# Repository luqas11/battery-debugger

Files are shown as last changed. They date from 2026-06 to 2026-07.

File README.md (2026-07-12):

# battery-debugger

A system for tracking the health of a lead-acid battery over time, by periodically measuring its discharge curve under a constant load. Comparing curves taken months apart reveals how much capacity the battery has lost.

## How it works

A discharge test goes like this:

1. Connect a fixed load and the ESP8266 board to the battery terminals.
2. Open the backend web UI and start a new test, entering the date, the load current, and the battery's age in months.
3. The ESP takes periodic voltage readings and sends them to the backend, which computes the elapsed time since the test started and saves both values to a CSV file.
4. Once the battery is depleted, stop the test from the web UI.
5. Push the new records to the repository — the dashboard on GitHub Pages updates automatically.

## Parts of the project

### `firmware/`

An Arduino sketch for the **ESP8266** that periodically reads the battery voltage through the analog input and sends it to the backend. The WiFi credentials, the backend URL, and the reading interval are configured at runtime via a built-in setup portal, with no reflashing needed. Two external LEDs indicate the connection and reading status. See [`firmware/README.md`](firmware/README.md) for setup, wiring, and calibration details.

### `circuit/`

KiCad schematic for the circuit that connects the ESP8266 board to the battery terminals, plus a 3D-printable case. A PDF export of the schematic is available at [`circuit/circuit-schematic.pdf`](circuit/circuit-schematic.pdf). See [`circuit/README.md`](circuit/README.md) for details.

### `backend/`

A **Go** backend (single static binary) that exposes an HTTP API to start and stop tests and receive voltage readings, and serves a web UI to control everything from a browser. It runs on the machine where records are stored. Supports Linux (32-bit and 64-bit) and Windows. See [`backend/README.md`](backend/README.md).

### `frontend/`

A **Go** tool that reads the `records/` folder and generates a static dashboard, published to **GitHub Pages**. The dashboard lets you compare discharge curves between tests and visualize battery capacity decay over time. See [`frontend/README.md`](frontend/README.md).

### `records/`

CSV and JSON files for every finished test. Each test produces a `<name>.csv` (time/voltage readings) and a `<name>.json` (date, current, battery age, and an `outlier` flag that excludes anomalous tests from the capacity decay chart). This folder is the single source of data for both the backend and the dashboard.

## Running the backend

Prebuilt binaries are in `backend/binaries/`. Run the one that matches your machine:

```
# Linux 32-bit
./backend/binaries/backend-386

# Linux 64-bit
./backend/binaries/backend-amd64

# Windows
.\backend\binaries\backend.exe
```

On Linux, mark the binary as executable first if needed: `chmod +x backend/binaries/backend-386`.

Once running, open `http://<host>:8000/` in a browser to access the web UI.

## Viewing the dashboard

The dashboard is published automatically to GitHub Pages on every push to `main` that modifies `records/` or `frontend/`. To view it locally, run:

```
./frontend/binaries/frontend.exe        # Windows
./frontend/binaries/frontend-amd64     # Linux 64-bit
./frontend/binaries/frontend-386       # Linux 32-bit
```

Then open `http://localhost:8001/`.

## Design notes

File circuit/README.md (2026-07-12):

# Circuit

KiCad schematic for the circuit that connects the ESP8266 board to the battery terminals. A PDF export is available at [`circuit-schematic.pdf`](circuit-schematic.pdf).

## What it does

- **Voltage divider** (R1 10k / R2 56k) scales the battery voltage down to a range the ESP8266's analog input (`A0`) can read safely. The firmware converts the raw ADC reading back to the real battery voltage using the `REF_VOLTAGE`/`REF_ADC` calibration constants — see [`../firmware/README.md`](../firmware/README.md).
- **Two status LEDs** (green and red), each behind a 220 Ω current-limiting resistor, connected to GPIO4 and GPIO12. These indicate the WiFi connection and last-reading status — see the LED indicators table in [`../firmware/README.md`](../firmware/README.md).
- **J1** is the two-pin connector to the battery terminals.

## Case

`Case.scad` is an OpenSCAD model for a 3D-printable enclosure, with `Case_Base.stl` and `Case_Lid.stl` as the exported, ready-to-print parts.

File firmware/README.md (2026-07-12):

# Firmware

An Arduino sketch for the **ESP8266** that periodically reads the battery voltage through the analog input and sends it to the backend, at a configurable interval (2 minutes by default).

## Setup

### 1. Configure the setup access point

Copy `config.example.h` to `config.h` and set the SSID and password for the access point the ESP exposes when configuring WiFi:

```cpp
#define AP_SSID     "SSID"
#define AP_PASSWORD "PASSWORD"
```

The password must be at least 8 characters (WPA2 requirement). `config.h` is gitignored and never committed.

### 2. Flash the sketch

Open `firmware.ino` in the Arduino IDE, select your ESP8266 board, and upload.

### 3. Configure via the setup portal

On first boot, the ESP starts a WiFi network using the SSID and password from `config.h`. Connect to it and open `http://192.168.4.1` in a browser.

The page has two independent configuration sections:

- **Configurar WiFi** — enter your network's SSID and password and press **Guardar**. The ESP saves the credentials and connects. Leaving the password field blank when re-saving the same network keeps the previously saved password.
- **Configurar backend** — enter the host and port of the machine running the backend (e.g. `192.168.1.42:8000`) and the reading interval in minutes, then press **Guardar**. The interval takes effect immediately, without a restart.

The setup portal stays available at `http://192.168.4.1` after a successful connection, so you can check the connection status, see the ESP's IP on the local network, or update any setting without reflashing.

## Voltage calibration

The voltage is converted from the ADC reading using two calibration constants defined directly in `firmware.ino`:

```cpp
const float REF_VOLTAGE = 11.46;  // known input voltage in Volts
const int   REF_ADC     = 566;    // ADC reading at that voltage
```

The conversion is: `voltage = analogRead(A0) * (REF_VOLTAGE / REF_ADC)`

To recalibrate, apply a known voltage to the input (close to the voltages you expect to measure for best accuracy), read the raw ADC value from the Serial monitor, and update both constants.

## LED indicators

The firmware uses two external LEDs connected to GPIO4 (green) and GPIO12 (red). Wire each LED with a resistor (~220–330 Ω) between the GPIO pin and the anode; connect the cathode to GND.

| Green LED | Red LED | Meaning |
|---|---|---|
| Blinking | Off | Connecting to WiFi |
| Solid | Off | Connected, last reading OK |
| Solid | Blinking | Connected, error sending last reading |
| Off | Solid | No WiFi connection |

## Dependencies

- **ArduinoJson 7.4.3** (Benoit Blanchon) — available in the Arduino Library Manager
- **ESP8266 Arduino Core 3.1.2** (ESP8266 Community) — available in the Arduino Boards Manager

If the code fails to compile after reinstalling dependencies, make sure the versions listed above are used.

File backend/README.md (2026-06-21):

# Backend

This **Go** backend handles all the logic related to running and saving battery discharge tests. It has no external dependencies (standard library only), and serves both the **HTTP API** and the **frontend** (embedded via `go:embed`) from a single static binary, with no runtime required on the target machine.

The working flow is the following: when a new test is started, a **CSV** file and a **JSON** metadata file are created, both named by appending the string `current_` to the given test name. Any saved reading is appended to that **CSV** file. When the test is ended, both files are renamed, removing the `current_` prefix. After that, the test's name appears in the test list, and its metadata and readings remain in the `/records` folder.

### API:

`[GET] /get-current-test`

Returns the name of the test that is currently in progress. If a test is in progress, returns:
```json
{
    "currentTestName": "Example",
    "metadata": { "date": "2026-06-14", "current": 0.25, "age": 12, "outlier": false },
    "lastReadings": [
        { "time": 1.50, "voltage": 12.10 },
        { "time": 1.53, "voltage": 12.05 }
    ]
}
```
If not, returns:
```json
{
    "currentTestName": ""
}
```

`[GET] /get-test-list`

Returns a list with the names of the finished tests saved in the `/records` folder. For example:
```json
{
    "testNames": [
        "Example",
        "Example2",
        "Example3"
    ]
}
```

`[POST] /start-test`

Starts a new test on the backend. The given name can only contain numbers, letters and underscores, and cannot be a name already present in the test list. `date` must have the format `YYYY-MM-DD`, and `current`/`age` must be numbers. The request body must be:
```json
{
    "name": "Example",
    "date": "2026-06-14",
    "current": 0.25,
    "age": 12
}
```

`[POST] /save-reading`

Saves a voltage reading to the current test file. The request body must be:
```json
{
    "voltage": 12.0
}
```

The time elapsed since the test started is computed by the backend and written to the CSV alongside the voltage. This makes the recorded time independent of when the ESP was booted, and robust to ESP reboots mid-test.

`[POST] /end-test`

Ends the test that is currently in progress.

### Development notes:

To run the app in development:
```
go run .
```

The server listens on port `8000` by default, on all network interfaces. This can be configured with environment variables:
- `PORT` — port to listen on (default `8000`)
- `HOST` — interface to bind to (default empty, i.e. all interfaces)

For example, to use a different port:
```
PORT=9000 go run .
```

### Building:

The app compiles to a single static binary, with no external dependencies. Always build with `CGO_ENABLED=0` to ensure the binary doesn't link against system libraries.

Prebuilt binaries for the supported targets are kept in the `binaries/` folder:

| Target | Binary | Build command |
|---|---|---|
| Ubuntu (32-bit, `i686`) | `binaries/backend-386` | `CGO_ENABLED=0 GOOS=linux GOARCH=386 go build -o binaries/backend-386 .` |
| Ubuntu (64-bit, `x86_64`) | `binaries/backend-amd64` | `CGO_ENABLED=0 GOOS=linux GOARCH=amd64 go build -o binaries/backend-amd64 .` |
| Windows (64-bit) | `binaries/backend.exe` | `CGO_ENABLED=0 GOOS=windows GOARCH=amd64 go build -o binaries/backend.exe .` |

Any of these binaries can be copied to and run on the corresponding target machine directly, without installing Go or any other dependency. The binary automatically locates the `/records` folder at the project root, whether it's run from `backend/` or from `backend/binaries/`.

### Running:

On Linux, the binary needs execute permissions, which may be lost when copying it from another OS:
```
chmod +x binaries/backend-386
```

To run a binary, either from `backend/`:
```
./binaries/backend-386
```
or from within `backend/binaries/`:
```
./backend-386
```
(on Windows, `.\binaries\backend.exe` or `.\backend.exe` respectively).

Once running, open `http://<host>:<port>/` in a browser (e.g. `http://localhost:8000/` or `http://192.168.1.11:8000/` from another machine on the same network) to access the web UI.

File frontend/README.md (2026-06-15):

# Frontend

This **Go** module generates the data for, and serves, a static dashboard that visualizes the battery discharge tests saved in `/records`: a comparison of voltage curves between tests, and the decay of estimated battery capacity over time.

It has no external dependencies (standard library only). The dashboard uses **Chart.js** loaded from a CDN, with no build step or npm involved.

### How it works:

Running the binary with no arguments does two things:
1. **Generates the data**: reads `/records`, and for every finished test (a matching `<name>.csv` + `<name>.json` pair) copies both files into `frontend/data/`, and writes `frontend/data/manifest.json` with a list of all tests and their metadata.
2. **Serves the dashboard**: starts an HTTP server serving the `frontend/` folder (including the `data/` just generated), so `index.html` can fetch the manifest and CSV/JSON files directly.

`frontend/data/` is regenerated on every run and is not committed to the repository (see `.gitignore`).

Running the binary with the `generate-data` subcommand only performs step 1, without starting the server. This is the mode used by the GitHub Actions workflow that deploys the dashboard to GitHub Pages.

### Development notes:

To run in development (generates data and serves on `:8001`):
```
go run .
```

To only generate `frontend/data/` without serving:
```
go run . generate-data
```

The server listens on port `8001` by default, on all network interfaces. This can be configured with environment variables:
- `PORT` — port to listen on (default `8001`)
- `HOST` — interface to bind to (default empty, i.e. all interfaces)

### Building:

The app compiles to a single static binary, with no external dependencies. Always build with `CGO_ENABLED=0` to ensure the binary doesn't link against system libraries.

Prebuilt binaries for the supported targets are kept in the `binaries/` folder:

| Target | Binary | Build command |
|---|---|---|
| Ubuntu (32-bit, `i686`) | `binaries/frontend-386` | `CGO_ENABLED=0 GOOS=linux GOARCH=386 go build -o binaries/frontend-386 .` |
| Linux (64-bit, used by CI) | `binaries/frontend-amd64` | `CGO_ENABLED=0 GOOS=linux GOARCH=amd64 go build -o binaries/frontend-amd64 .` |
| Windows (64-bit) | `binaries/frontend.exe` | `CGO_ENABLED=0 GOOS=windows GOARCH=amd64 go build -o binaries/frontend.exe .` |

The binary automatically locates `/records` and the `frontend/` folder, whether it's run from `frontend/` or from `frontend/binaries/`.

### Running:

On Linux, the binary needs execute permissions, which may be lost when copying it from another OS:
```
chmod +x binaries/frontend-amd64
```

To run a binary, either from `frontend/`:
```
./binaries/frontend-amd64
```
or from within `frontend/binaries/`:
```
./frontend-amd64
```
(on Windows, `.\binaries\frontend.exe` or `.\frontend.exe` respectively).

Once running, open `http://localhost:8001/` in a browser to view the dashboard.

### Deployment:

The dashboard is published to GitHub Pages via `.github/workflows/deploy-frontend.yml`, which runs on every push to `main` that touches `records/` or `frontend/`. It runs `binaries/frontend-amd64 generate-data` to populate `frontend/data/`, then publishes the `frontend/` folder as a Pages artifact.

For this to work, GitHub Pages must be configured with **Source: GitHub Actions** in the repository settings.

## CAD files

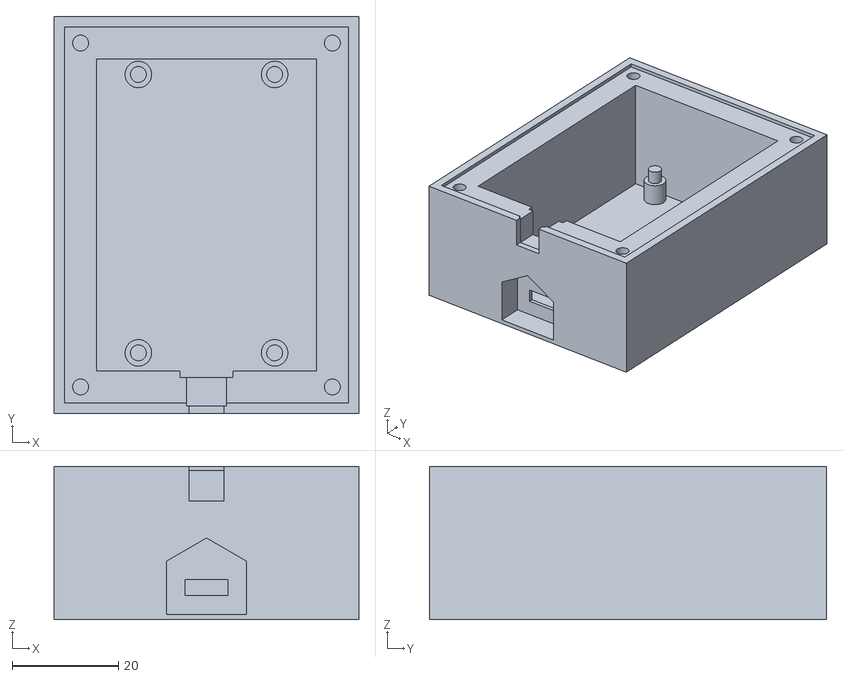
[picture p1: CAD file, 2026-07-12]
circuit/Case_Base.stl
57.3 x 74.6 x 28.8

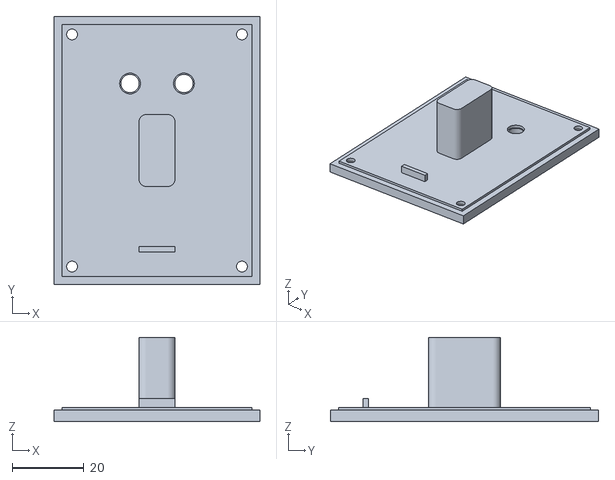
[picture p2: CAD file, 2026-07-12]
circuit/Case_Lid.stl
57.3 x 74.6 x 23.5

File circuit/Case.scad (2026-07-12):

/* ============================================================
   BATTERY DEBUGGER - Case para NodeMCU V3
   ============================================================
   Apertura: tornillos autorroscantes (4 esquinas)
   Sujecion de la placa: tipo "sandwich" sobre postes que tambien
                          centran la placa en X/Y (encajan a
                          presion en los agujeros de montaje)
   LEDs: agujero a presion sin pegamento (escalon que traba el
         reborde/flange del LED)
   Puerto USB: hueco recesado (carcasa del conector macho + agujero
               del tamaño exacto del conector), con ranura de
               montaje oculta detras de una pared fina

   COMO IMPRIMIR:
   Cambia la variable render_part (arriba de todo, antes de los demas
   parametros) para elegir que renderizar/exportar: "base", "lid" o "both".
   Con "both" se dibujan las dos piezas lado a lado, utiles para ver el
   conjunto en preview, pero para exportar STL conviene exportar cada
   pieza por separado (con "base" o "lid").
   ============================================================ */

// ---------- QUE RENDERIZAR ----------
render_part = "both";  // "base" | "lid" | "both"

// ---------- PLACA (NodeMCU V3) ----------
board_length          = 58;     // mm, eje Y (largo)
board_width           = 31.3;   // mm, eje X (ancho)
board_height          = 20;     // mm, altura total con componentes + espacio para cablear LEDs adentro
mount_hole_dia        = 3.2;    // diametro de los agujeros de montaje de la placa
mount_hole_offset_x   = 2.85;   // centro del agujero al borde de la placa, sentido del lado corto (ancho)
mount_hole_offset_y   = 2.6;    // centro del agujero al borde de la placa, sentido del lado largo (largo)
peg_near_usb_extra    = 0.5;    // mm de mas para alejar de la pared los 2 postes del lado del conector
                                 // (sacrifica un poco de alineacion con el agujero real, a cambio de mas margen)

// ---------- TOLERANCIAS Y PAREDES ----------
wall                  = 2.0;    // espesor de pared
board_gap_usb_side    = 0.3;    // juego entre la placa y la cavidad, lado del conector USB -- debe quedar al ras
board_gap_far_side    = board_gap_usb_side;  // lado opuesto al USB -- igual al del USB, para que sea simetrico
board_gap_x_sides     = 5.0;    // margen entre la placa y la cavidad en los 2 lados X (izq/der) -- de sobra, sin ajuste fino
top_clearance         = 1.0;    // espacio libre entre el componente mas alto y la tapa
margin                = 6.0;    // franja libre entre la cavidad y la pared externa (para los postes de tornillo)

// ---------- POSTES DE CENTRADO / STANDOFF (sandwich) ----------
peg_height            = 5.0;    // altura del cilindro ancho (separacion piso<->placa)
peg_base_dia          = 5.0;    // diametro del cilindro ancho (mas resistente, evita que
                                 // los componentes de la placa hagan presion contra el piso)
peg_tip_height        = 3.0;    // altura de la punta fina que entra en el agujero de la placa
peg_tip_dia           = mount_hole_dia - 0.2;  // un poco menor a mount_hole_dia -> encaja a presion
board_thickness       = 1.0;    // espesor real de la PCB (sin componentes, que miran hacia el piso)

// ---------- POSTE DE PRESION (colgante desde la tapa, unico y central) ----------
// Empuja la placa contra los postes de centrado al cerrar, sin ocupar
// espacio en las esquinas ni en la mayor parte del volumen de cableado.
press_post_w          = 10.0;   // ancho del poste de presion (eje X)
press_post_l          = 20.0;   // largo del poste de presion (eje Y)
press_post_corner_r   = 2.0;    // radio de redondeo de los 4 bordes verticales del poste
press_post_overlap    = -0.5;   // mm de mas (o de menos, si es negativo) que el poste se pasa hacia
                                 // la placa -- negativo = queda corto a proposito, para no presionar de mas

// ---------- TORNILLOS AUTORROSCANTES (tapa) ----------
screw_pilot_dia       = 3.0;    // agujero piloto para que el tornillo se muerda
screw_pilot_depth     = 8.0;    // profundidad del agujero piloto dentro del poste
screw_shaft_clear_dia = 3.0;    // hueco en la tapa para que pase el cuerpo del tornillo
screw_head_clear_dia  = 6.4;    // hueco para la cabeza del tornillo (avellanado) -- cabeza real 6mm + 0.4mm de juego
screw_head_depth      = 3.0;    // profundidad del avellanado -- altura real de la cabeza conica del tornillo

// ---------- REGISTRO DE LA TAPA (centrado) ----------
rabbet_height       = 0.8;  // alto del escalon de registro, en todo el borde superior
rabbet_width        = 2.0;  // ancho de ese escalon (banda a lo largo del borde)
rabbet_clearance    = 0.2;  // juego entre el escalon de la base y el hueco de la tapa

// ---------- USB (pared frontal, y=0) ----------
usb_cutout_w                    = 8;    // ancho de la abertura -- igual al ancho real del conector
usb_cutout_h                    = 3;    // alto de la abertura -- igual al alto real del conector
usb_x_offset                    = 0;    // +/- mm si el puerto no esta centrado -- VERIFICAR
usb_z_adjust                    = -0.5; // mm, cuanto mas abajo del nivel de la placa (floor_thickness+peg_height)
                                         // queda la cara superior del hueco -- negativo = queda mas arriba.
                                         // Ajustado tras la 2da impresion y prueba.
usb_connector_overhang          = 1.5;  // mm, cuanto sobresale el conector del borde de la placa
usb_cover_thickness             = 1.0;  // espesor de la pared que tapa la ranura, ubicada al ras de la punta del conector
usb_plug_housing_w              = 15;   // ancho del hueco para la carcasa plastica del conector macho (desde afuera)
usb_plug_housing_h              = 10;   // alto del hueco para la carcasa plastica del conector macho (desde afuera)
usb_plug_roof_angle             = 60;   // grados desde la vertical del chaflan que reemplaza el techo plano
                                         // (mas chico = pared mas parada = mejor para imprimir sin soporte)
usb_relief_w                    = 10;   // ancho de la ranura interna de alivio (lado de la cavidad)

// ---------- LEDs (en la tapa) ----------
led_dia          = 5.0;   // diametro del LED (dado: 5mm)
led_through_dia  = led_dia + 0.1;  // agujero exterior, el cuerpo del LED pasa a ras
led_flange_dia   = 5.8;   // diametro del reborde/flange del LED -- VERIFICAR (varia segun el fabricante)
led_flange_depth = 1.0;   // profundidad del escalon donde se traba el reborde

// ---------- CONECTOR EMBUTIDO (pared frontal, arriba del USB) ----------
// Conector tipo JST embutido en la pared, con el socket mirando hacia
// afuera (para enchufar un cable desde afuera) y los pines mirando hacia
// adentro (para cablear directo a la placa). Retencion en las 2
// direcciones: una pared fina con ventana chica (el cuerpo no puede salir
// por ahi) + un tope colgando de la tapa (no puede hundirse hacia adentro).
conn_w                = 7.5;    // ancho del cuerpo del conector (medida real)
conn_h                = 5.7;    // alto del cuerpo del conector (medida real)
conn_h_clearance      = 0.5;    // margen extra en el alto del bolsillo, para que no quede tan justo -> 6.2mm en total
conn_d                = 7.1;    // profundidad del cuerpo del conector (medida real)
conn_d_clearance      = 0.5;    // margen extra en la profundidad -- en la practica no agranda el
                                 // bolsillo (esa zona ya es hueca por la cavidad), solo corre el
                                 // tope 0.5mm mas adentro
conn_cover_thickness  = 1.5;    // espesor de la pared fina, pegada a la cara exterior
conn_hole_clearance   = 0.5;    // mm de solape por lado entre el cuerpo y la ventana (retencion)
conn_stop_w           = 10.0;   // ancho del tope (cuelga de la tapa)
conn_stop_h           = 2.5;    // alto del tope
conn_stop_thickness   = 1.5;    // espesor del tope (eje Y)

// ---------- GENERAL ----------
floor_thickness  = 2.0;   // espesor del piso de la base
lid_thickness    = 4.0;   // espesor de la tapa -- suficiente para 3mm de avellanado + 1mm de material debajo
$fn = 32;                 // resolucion de los cilindros

// ============================================================
// CALCULOS DERIVADOS (no tocar salvo que sepas lo que haces)
// ============================================================
cavity_w   = board_width + 2*board_gap_x_sides;                        // ambos lados en X usan el gap de los lados X
cavity_l   = board_length + board_gap_usb_side + board_gap_far_side;   // Y: lado USB (cerca) y lado opuesto (lejos), ahora simetricos
ext_w      = cavity_w + 2*margin + 2*wall;
ext_l      = cavity_l + 2*margin + 2*wall;
wall_height = peg_height + board_height + top_clearance;
case_top    = floor_thickness + wall_height;       // altura de las paredes/postes, sin el escalon de registro
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

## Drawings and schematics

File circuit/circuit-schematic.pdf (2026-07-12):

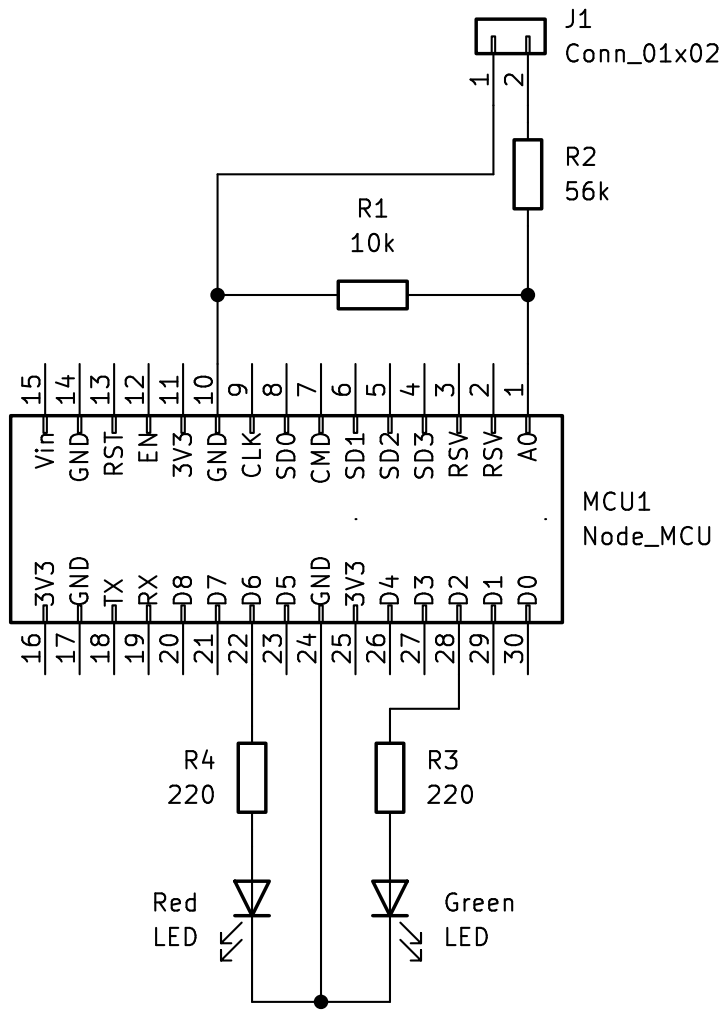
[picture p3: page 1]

1 GND 10 3V3 11 EN 12 RST 13 GND 14 Vin 15 3V3 16 GND 17 TX 18 RX 19 RSV

Id: 1/1 Title: Battery Debugger File: circuit.kicad_sch Sheet: /

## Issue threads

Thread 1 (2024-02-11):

Add wiring schematic

luqas11, 2024-02-11:
The wiring of the NodeMCU si fairly simple, but a circuit schematic should be added to the repo to make it clear and avoid future mistakes.

Closed 2024-12-24.

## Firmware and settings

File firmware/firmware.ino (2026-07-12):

#include <ESP8266WiFi.h>
#include <ESP8266HTTPClient.h>
#include <ESP8266WebServer.h>
#include <LittleFS.h>
#include <ArduinoJson.h>
#include "config.h"

const float REF_VOLTAGE = 11.46;
const int   REF_ADC     = 566;

const int           LED_GREEN_PIN       = 4;   // GPIO4  — external green LED (active HIGH)
const int           LED_RED_PIN         = 12;  // GPIO12 — external red LED   (active HIGH)
const unsigned long WIFI_TIMEOUT_MS     = 10000UL;
const char*         CONFIG_PATH         = "/config.json";
const unsigned long DEFAULT_INTERVAL_MS = 120000UL;

ESP8266WebServer server(80);

String        savedSSID;
String        savedPassword;
String        savedServerHost;
unsigned long readingIntervalMs = DEFAULT_INTERVAL_MS;
unsigned long lastSentAt        = DEFAULT_INTERVAL_MS; // triggers immediately on first loop

// ── LED state ─────────────────────────────────────────────────────────────────

enum LedState { CONNECTING, CONNECTED_OK, CONNECTED_ERROR, NO_WIFI };
LedState      ledState        = CONNECTING;
unsigned long lastLedBlinkMs  = 0;
bool          ledBlinkToggle  = false;

void setLedState(LedState state) {
  ledState       = state;
  ledBlinkToggle = false;
  lastLedBlinkMs = 0;
}

void updateLeds() {
  unsigned long now = millis();
  switch (ledState) {
    case CONNECTING:
      if (now - lastLedBlinkMs >= 500) {
        ledBlinkToggle = !ledBlinkToggle;
        digitalWrite(LED_GREEN_PIN, ledBlinkToggle ? HIGH : LOW);
        digitalWrite(LED_RED_PIN, LOW);
        lastLedBlinkMs = now;
      }
      break;
    case CONNECTED_OK:
      digitalWrite(LED_GREEN_PIN, HIGH);
      digitalWrite(LED_RED_PIN,   LOW);
      break;
    case CONNECTED_ERROR:
      digitalWrite(LED_GREEN_PIN, HIGH);
      if (now - lastLedBlinkMs >= 500) {
        ledBlinkToggle = !ledBlinkToggle;
        digitalWrite(LED_RED_PIN, ledBlinkToggle ? HIGH : LOW);
        lastLedBlinkMs = now;
      }
      break;
    case NO_WIFI:
      digitalWrite(LED_GREEN_PIN, LOW);
      digitalWrite(LED_RED_PIN,   HIGH);
      break;
  }
}

// ── Config (LittleFS) ─────────────────────────────────────────────────────────

bool loadConfig() {
  File f = LittleFS.open(CONFIG_PATH, "r");
  if (!f) return false;

  JsonDocument doc;
  if (deserializeJson(doc, f)) { f.close(); return false; }
  f.close();

  savedSSID         = doc["ssid"]       | "";
  savedPassword     = doc["password"]   | "";
  savedServerHost   = doc["serverHost"] | "";
  readingIntervalMs = doc["intervalMs"] | DEFAULT_INTERVAL_MS;
  return savedSSID.length() > 0;
}

bool saveConfig(const String& ssid, const String& password, const String& serverHost) {
  File f = LittleFS.open(CONFIG_PATH, "w");
  if (!f) return false;

  JsonDocument doc;
  doc["ssid"]        = ssid;
  doc["password"]    = password;
  doc["serverHost"]  = serverHost;
  doc["intervalMs"]  = readingIntervalMs;
  serializeJson(doc, f);
  f.close();
  return true;
}

// ── WiFi ──────────────────────────────────────────────────────────────────────

bool connectWiFi(const String& ssid, const String& password) {
  WiFi.begin(ssid.c_str(), password.c_str());

  unsigned long start  = millis();
  bool          toggle = false;
  while (WiFi.status() != WL_CONNECTED) {
    if (millis() - start > WIFI_TIMEOUT_MS) {
      WiFi.disconnect();
      return false;
    }
    toggle = !toggle;
    digitalWrite(LED_GREEN_PIN, toggle ? HIGH : LOW);
    digitalWrite(LED_RED_PIN, LOW);
    delay(500);
  }
  return true;
}

// ── Web server ────────────────────────────────────────────────────────────────

const char PAGE_STYLE[] PROGMEM = R"css(
  *, *::before, *::after { box-sizing: border-box; }
  body {
    margin: 0;
    min-height: 100vh;
    background-color: #121212;
    color: #e0e0e0;
    font-family: system-ui, -apple-system, "Segoe UI", Roboto, sans-serif;
    display: flex;
    justify-content: center;
    padding: 32px 16px;
  }
  .container { width: 100%; max-width: 400px; }
  h1 { margin: 0 0 4px; font-size: 1.8rem; text-align: center; }
  .subtitle { color: #9a9a9a; font-size: 0.95rem; text-align: center; margin: 0 0 24px; }
  .card {
    background-color: #222222;
    border-radius: 12px;
    padding: 20px;
    box-shadow: 0 4px 12px rgba(0,0,0,0.4);
    margin-bottom: 16px;
  }
  .card h2 { margin: 0 0 12px; font-size: 1.1rem; }
  label { display: block; font-size: 0.85rem; color: #9a9a9a; margin-bottom: 4px; }
  input {
    width: 100%;
    padding: 8px 10px;
    margin-bottom: 14px;
    background-color: #2c2c2c;
    border: 1px solid #444444;
    border-radius: 6px;
    color: #e0e0e0;
    font-size: 0.95rem;
  }
  input:focus { outline: none; border-color: #64b5f6; }
  button {
    width: 100%;
    padding: 10px;
    background: #4caf50;
    color: #121212;
    border: none;
    font-size: 0.95rem;
    font-weight: 600;
    cursor: pointer;
    border-radius: 6px;
  }
  button:hover { background: #66bb6a; }
  .row { display: flex; justify-content: space-between; align-items: center;
         padding: 6px 0; border-bottom: 1px solid #333333; font-size: 0.9rem; }
  .row:last-child { border-bottom: none; }
  .row .label { color: #9a9a9a; }
  .connected    { color: #4caf50; font-weight: 600; }
  .disconnected { color: #e57373; font-weight: 600; }
  .not-set      { color: #9a9a9a; font-style: italic; }
)css";

void handleRoot() {
  bool connected = WiFi.status() == WL_CONNECTED;

  String statusCard = "<div class=\"card\"><h2>Estado de conexión</h2>";
  statusCard += "<div class=\"row\"><span class=\"label\">Estado</span>"
                "<span class=\"" + String(connected ? "connected" : "disconnected") + "\">"
                + String(connected ? "Conectado" : "No conectado") + "</span></div>";
  if (connected) {
    statusCard += "<div class=\"row\"><span class=\"label\">Red</span><span>" + WiFi.SSID() + "</span></div>";
    statusCard += "<div class=\"row\"><span class=\"label\">IP</span><span>" + WiFi.localIP().toString() + "</span></div>";
  } else if (savedSSID.length() > 0) {
    statusCard += "<div class=\"row\"><span class=\"label\">Última red</span><span>" + savedSSID + "</span></div>";
  }
  statusCard += "<div class=\"row\"><span class=\"label\">Backend</span><span>"
                + (savedServerHost.length() > 0
                    ? savedServerHost
                    : String("<span class=\"not-set\">No configurado</span>"))
                + "</span></div>";
  statusCard += "<div class=\"row\"><span class=\"label\">Intervalo</span><span>"
                + String(readingIntervalMs / 60000) + " min</span></div>";
  statusCard += "</div>";

  String wifiForm = "<div class=\"card\"><h2>Configurar WiFi</h2>"
                   "<form method=\"POST\" action=\"/save-wifi\">"
                   "<label>SSID</label>"
                   "<input name=\"ssid\" type=\"text\" autocomplete=\"off\" value=\"" + savedSSID + "\">"
                   "<label>Password</label>"
                   "<input name=\"password\" type=\"password\">"
                   "<button type=\"submit\">Guardar</button>"
                   "</form></div>";

  String backendForm = "<div class=\"card\"><h2>Configurar backend</h2>"
                      "<form method=\"POST\" action=\"/save-backend\">"
                      "<label>Backend URL</label>"
                      "<input name=\"serverHost\" type=\"text\" placeholder=\"192.168.1.X:8000\" value=\"" + savedServerHost + "\">"
                      "<label>Intervalo de lectura (minutos)</label>"
                      "<input name=\"intervalMin\" type=\"number\" min=\"1\" value=\"" + String(readingIntervalMs / 60000) + "\">"
                      "<button type=\"submit\">Guardar</button>"
                      "</form></div>";

  String page = "<!DOCTYPE html><html><head><meta charset=\"utf-8\">"
                "<meta name=\"viewport\" content=\"width=device-width, initial-scale=1\">"
                "<title>Battery Debugger</title>"
                "<style>" + String(FPSTR(PAGE_STYLE)) + "</style></head>"
                "<body><div class=\"container\">"
                "<h1>Battery Debugger</h1>"
                "<p class=\"subtitle\">ESP8266 Setup</p>"
                + statusCard + wifiForm + backendForm +
                "</div></body></html>";

  server.send(200, "text/html", page);
}

String errorPage(const String& msg) {
  return String("<!DOCTYPE html><html><head><meta charset=\"utf-8\">"
                "<meta name=\"viewport\" content=\"width=device-width,initial-scale=1\">"
                "<title>Battery Debugger</title></head>"
                "<body style=\"background:#121212;color:#e0e0e0;font-family:system-ui,sans-serif;"
                "display:flex;justify-content:center;padding:32px 16px\">"
                "<div style=\"max-width:400px;width:100%\">"
                "<p style=\"color:#e57373\">") + msg +
         String("</p><a href=\"/\" style=\"color:#64b5f6\">Volver</a></div></body></html>");
}

void handleSaveWiFi() {
  String ssid     = server.arg("ssid");
  String password = server.arg("password");

  if (ssid.length() == 0) {
    server.send(400, "text/html", errorPage("El SSID no puede estar vacío."));
    return;
  }

  // If the password is left blank for the same network, keep the saved one.
  // A blank password for a different network is treated as an open network.
  if (password.length() == 0 && ssid == savedSSID) password = savedPassword;

  if (!saveConfig(ssid, password, savedServerHost)) {
    server.send(500, "text/html", errorPage("Error al guardar la configuración."));
    return;
  }

  savedSSID     = ssid;
  savedPassword = password;

  // Respond before attempting to connect: connectWiFi blocks for up to 10s,
  // and the browser would hang waiting for this response otherwise.
  server.sendHeader("Location", "/");
  server.send(303);

  if (WiFi.SSID() != ssid || WiFi.status() != WL_CONNECTED) {
    WiFi.disconnect();
    setLedState(CONNECTING);
    if (connectWiFi(ssid, password)) {
      setLedState(CONNECTED_OK);
      Serial.println("WiFi connected: " + WiFi.localIP().toString());
    } else {
      setLedState(NO_WIFI);
      Serial.println("WiFi connection failed");
    }
  }
}

void handleSaveBackend() {
  String serverHost  = server.arg("serverHost");
  String intervalStr = server.arg("intervalMin");

  if (intervalStr.length() > 0) {
    int mins = intervalStr.toInt();
    if (mins < 1) {
      server.send(400, "text/html", errorPage("El intervalo debe ser un número entero de minutos, mayor o igual a 1."));
      return;
    }
    readingIntervalMs = (unsigned long)mins * 60000UL;
  }

  if (!saveConfig(savedSSID, savedPassword, serverHost)) {
    server.send(500, "text/html", errorPage("Error al guardar la configuración."));
    return;
  }

  savedServerHost = serverHost;

  server.sendHeader("Location", "/");
  server.send(303);

  Serial.println("Backend host updated: " + savedServerHost);
  Serial.println("Reading interval updated: " + String(readingIntervalMs / 60000) + " min");
}

void startServer() {
  server.on("/",             HTTP_GET,  handleRoot);
  server.on("/save-wifi",    HTTP_POST, handleSaveWiFi);
  server.on("/save-backend", HTTP_POST, handleSaveBackend);
  server.begin();
  Serial.println("Web server started at http://192.168.4.1");
}

// ── Reading ───────────────────────────────────────────────────────────────────

bool sendReading(float voltage) {
  WiFiClient client;
  HTTPClient http;

  String url = "http://" + savedServerHost + "/save-reading";
  http.begin(client, url);
  http.addHeader("Content-Type", "application/json");

  String body = "{\"voltage\":" + String(voltage, 4) + "}";
  int status = http.POST(body);
  http.end();

  return status == 200;
}

// ── Main ──────────────────────────────────────────────────────────────────────

void setup() {
  Serial.begin(115200);
  pinMode(LED_GREEN_PIN, OUTPUT);
  pinMode(LED_RED_PIN,   OUTPUT);
  setLedState(CONNECTING);
  updateLeds();

  if (!LittleFS.begin()) {
    Serial.println("LittleFS mount failed, formatting...");
    LittleFS.format();
    if (!LittleFS.begin()) {
      Serial.println("LittleFS mount failed after format");
    }
  }

  WiFi.mode(WIFI_AP_STA);
  WiFi.softAP(AP_SSID, AP_PASSWORD);
  Serial.println("AP started: " + String(AP_SSID));

  startServer();

  if (loadConfig()) {
    Serial.println("Connecting to: " + savedSSID);
    if (connectWiFi(savedSSID, savedPassword)) {
      setLedState(CONNECTED_OK);
      Serial.println("WiFi connected: " + WiFi.localIP().toString());
    } else {
      setLedState(NO_WIFI);
      Serial.println("WiFi connection failed, continuing in AP-only mode");
    }
  } else {
    setLedState(NO_WIFI);
    Serial.println("No config found, waiting for configuration via portal");
  }
}

void loop() {
  server.handleClient();
  updateLeds();

  if (WiFi.status() == WL_CONNECTED && savedServerHost.length() > 0
      && millis() - lastSentAt >= readingIntervalMs) {
    lastSentAt = millis();

    float inputValue   = analogRead(A0);
    float voltageValue = inputValue * (REF_VOLTAGE / REF_ADC);

    Serial.printf("Sending: voltage=%.4f\n", voltageValue);

    if (sendReading(voltageValue)) {
      Serial.println("OK");
      setLedState(CONNECTED_OK);
    } else {
      Serial.println("ERROR");
      setLedState(CONNECTED_ERROR);
    }
  }
}

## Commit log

2023-08-10 Basic project structure
    [example.csv]
2023-08-10 Update Postman collection with error cases
    [example.csv]
2023-08-12 Add voltage calculation
2023-08-15 Rename example files
    [Example1.csv]
2023-11-25 Add new measure
    [2023_11_24_Discharge.csv]
2024-12-24 Add circuit schematic
    [circuit.kicad_pcb, circuit.kicad_sch]
2024-12-24 Remove Arduino VSCode extension configuration
2024-12-24 Format firmware sketch with the Arduino IDE 2 auto formatter
2025-07-24 Add measure metadata
    [2025_07_23_Discharge.csv]
2025-07-24 Fix measure error
    [2025_07_23_Discharge.csv]
2026-06-15 Relocate historical data
    [2023_11_24_Discharge.csv, 2023_12_03_Discharge.csv, 2024_04_11_Discharge.csv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]
2026-06-16 Fix current texts to two decimals
2026-06-16 Fix format, security and reliability issues
    [firmware.ino]
2026-07-12 Add two state indicator leds
2026-07-12 Add error message and improve code structure
    [firmware.ino]
2026-07-12 Add indicator LEDs to circuit schematic
    [circuit.kicad_sch]
2026-07-12 Add 3D printable case files
    [Case.scad, Case_Base.stl, Case_Lid.stl]
2026-07-25 Add nuew measures
    [2026_07_25_Discharge.csv]
2026-07-29 Add new measures
    [2026_07_28_Discharge.csv]
